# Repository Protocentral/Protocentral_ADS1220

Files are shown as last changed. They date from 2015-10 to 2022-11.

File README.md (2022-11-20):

# ProtoCentral ADS1220 24-bit ADC Breakout Board


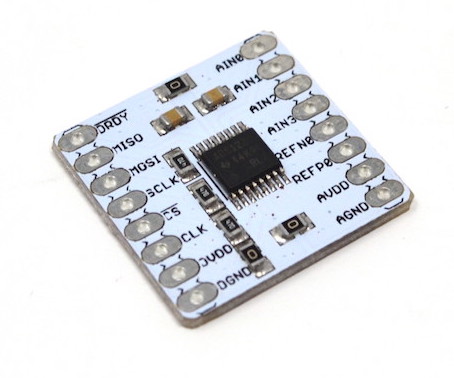
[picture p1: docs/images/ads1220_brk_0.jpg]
ADS1220 Breakout


If you don't already have one, you can buy the ProtoCentral ADS1220 24-bit ADC Breakout Board from: [ProtoCentral(Worldwide)](https://protocentral.com/product/ads1220-24-bit-4-channel-low-noise-adc-breakout-board/)

Why would you need a 24-bit ADC? When 16-bit is just not enough.
If your design demands high precision analog measurements, this new breakout board for the ADS1220 24-bit Sigma-delta ADC can get the job done.
Most of the previously available 24-bit ADCs have been difficult to use since they require a separate voltage reference and a lot of external components among other things. The ADS1220 gets rid of almost all external components with an internal voltage reference and internal clock. This is one of the easiest to use 24-bit ADCs that we have come across.
We also provide the Arduino libraries for interfacing this chip with your Arduino. To install the library, download the zip file from our github site, rename it to ProtoCentral_ADS1220 and unzip this file in your Arduino libraries folder.

## Features

* Programmable Data Rates: Up to 2 kSPS
* Programmable Gain: 1 V/V to 128 V/V
* Low current : 250 uA
* Low-Noise: 90 nVRMS at 20 SPS

## Applications

* High Precision analog voltage measurement
* RTD interfacing
* High precision chemical sensors

## Wiring to your Arduino

|ADS1220 Pin | Pin Function |Arduino Uno Pin Connection|
|---|:---:|---:|
| DRDY | Data ready Output pin|  D2 | 
| MISO | Slave Out |  D12 |
| MOSI | Slave In |  D11 |
| SCLK | Serial Clock |  D13 |
| CS | Chip Select |  D7 |
| DVDD | Digital VDD |  +5V |
| DGND | Digital Gnd |  Gnd |
| AN0-AN3 | Analog Input |  Analog Input |
| AVDD | Analog VDD |  - |
| AGND | Analog Gnd |  - |

  ** The example sketch is configured for internal Vref=2.048, provide the differential voltage across AN0 and AN1.

License Information
===================

License

This product is open source! Both, our hardware and software are open source and licensed under the following licenses:

Hardware
---------

**All hardware is released under the [CERN-OHL-P v2](https://ohwr.org/cern_ohl_p_v2.txt)** license.

Copyright CERN 2020.

This source describes Open Hardware and is licensed under the CERN-OHL-P v2.

You may redistribute and modify this documentation and make products
using it under the terms of the CERN-OHL-P v2 (https:/cern.ch/cern-ohl).
This documentation is distributed WITHOUT ANY EXPRESS OR IMPLIED
WARRANTY, INCLUDING OF MERCHANTABILITY, SATISFACTORY QUALITY
AND FITNESS FOR A PARTICULAR PURPOSE. Please see the CERN-OHL-P v2
for applicable conditions

Software
--------

**All software is released under the MIT License(http://opensource.org/licenses/MIT).**

THE SOFTWARE IS PROVIDED "AS IS", WITHOUT WARRANTY OF ANY KIND, EXPRESS OR IMPLIED, INCLUDING BUT NOT LIMITED TO THE WARRANTIES OF MERCHANTABILITY, FITNESS FOR A PARTICULAR PURPOSE AND NONINFRINGEMENT. IN NO EVENT SHALL THE AUTHORS OR COPYRIGHT HOLDERS BE LIABLE FOR ANY CLAIM, DAMAGES OR OTHER LIABILITY, WHETHER IN AN ACTION OF CONTRACT, TORT OR OTHERWISE, ARISING FROM, OUT OF OR IN CONNECTION WITH THE SOFTWARE OR THE USE OR OTHER DEALINGS IN THE SOFTWARE.

Documentation
-------------
**All documentation is released under [Creative Commons Share-alike 4.0 International](http://creativecommons.org/licenses/by-sa/4.0/).**


You are free to:

* Share — copy and redistribute the material in any medium or format
* Adapt — remix, transform, and build upon the material for any purpose, even commercially.
The licensor cannot revoke these freedoms as long as you follow the license terms.

Under the following terms:

* Attribution — You must give appropriate credit, provide a link to the license, and indicate if changes were made. You may do so in any reasonable manner, but not in any way that suggests the licensor endorses you or your use.
* ShareAlike — If you remix, transform, or build upon the material, you must distribute your contributions under the same license as the original.

Please check [*LICENSE.md*](LICENSE.md) for detailed license descriptions.

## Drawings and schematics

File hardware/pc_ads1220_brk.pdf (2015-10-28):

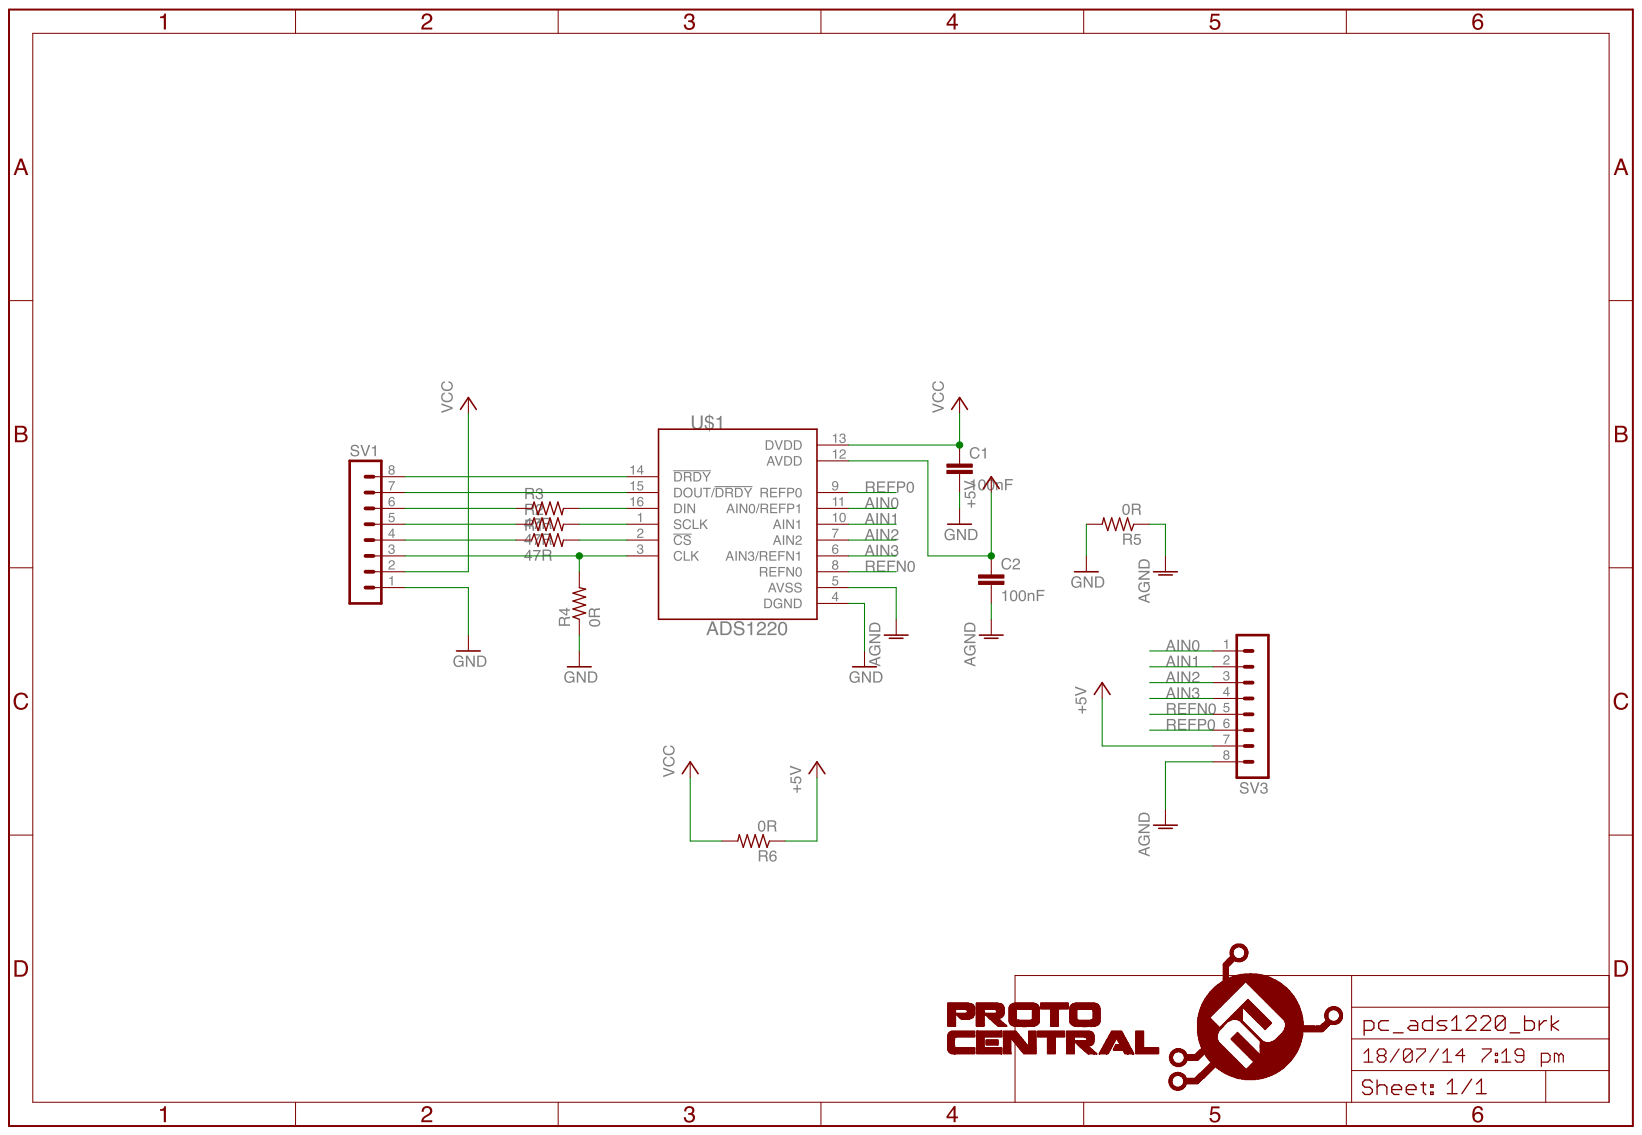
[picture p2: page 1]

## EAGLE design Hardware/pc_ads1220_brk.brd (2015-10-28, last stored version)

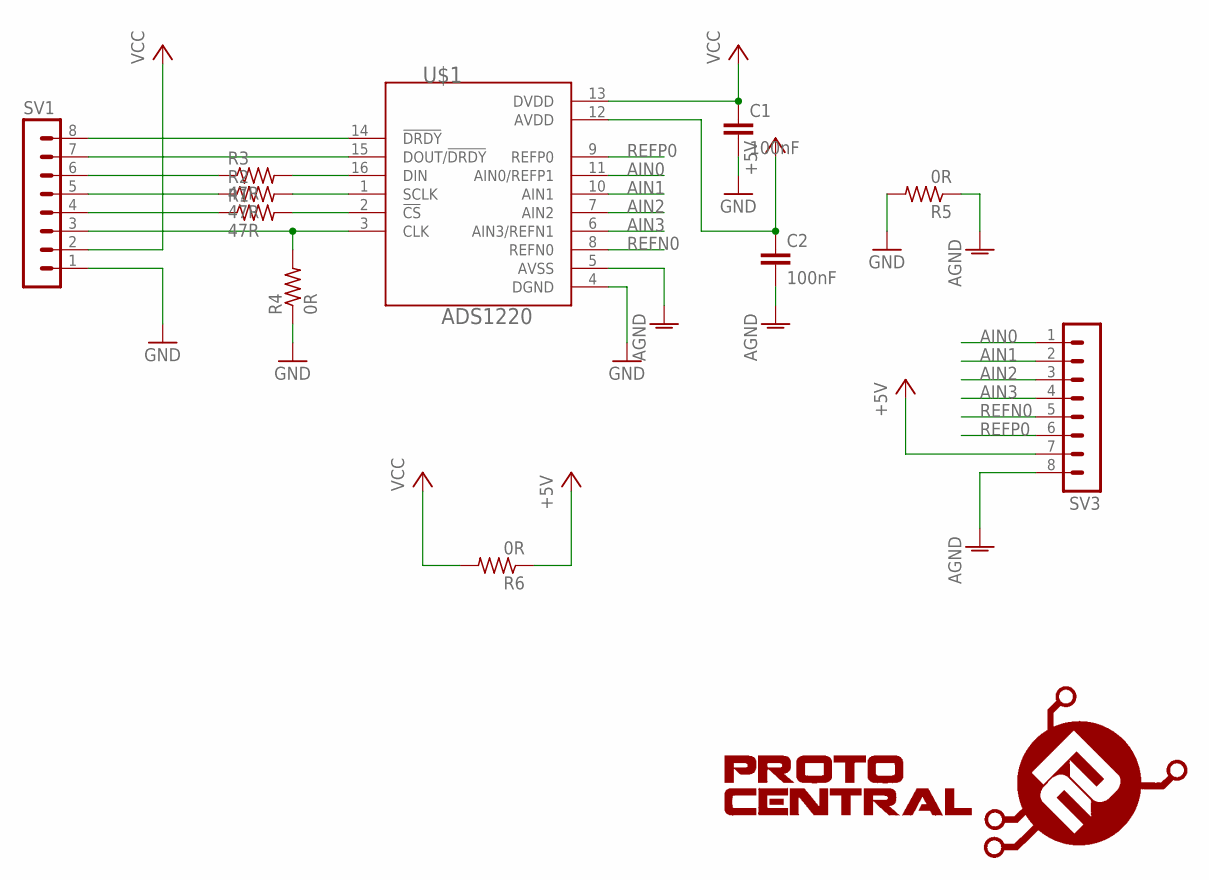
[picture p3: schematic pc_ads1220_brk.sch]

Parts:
C1, C2: 100nF; C0805
R1, R2, R3: 47R; R0805
R4, R5, R6: 0R; R0805
SV1, SV3: MA08-1
U$1: ADS1220; TSSOP-16
U$3: PROTY_LOGO_WITH_TEXT; PROTY_WITH_TEXT

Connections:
+5V: C2.1, R6.1, SV3.7, U$1.12 (AVDD)
AGND: C2.2, R5.1, SV3.8, U$1.5 (AVSS)
AIN0: SV3.1, U$1.11 (AIN0/REFP1)
AIN1: SV3.2, U$1.10 (AIN1)
AIN2: SV3.3, U$1.7 (AIN2)
AIN3: SV3.4, U$1.6 (AIN3/REFN1)
GND: C1.2, R4.1, R5.2, SV1.1, U$1.4 (DGND)
unnamed: R3.1, SV1.6
unnamed: R2.1, SV1.5
unnamed: R3.2, U$1.16 (DIN)
unnamed: R2.2, U$1.1 (SCLK)
unnamed: R1.2, U$1.2 (!CS)
unnamed: R1.1, SV1.4
unnamed: R4.2, SV1.3, U$1.3 (CLK)
unnamed: SV1.7, U$1.15 (DOUT/!DRDY)
unnamed: SV1.8, U$1.14 (!DRDY)
REFN0: SV3.5, U$1.8 (REFN0)
REFP0: SV3.6, U$1.9 (REFP0)
VCC: C1.1, R6.2, SV1.2, U$1.13 (DVDD)

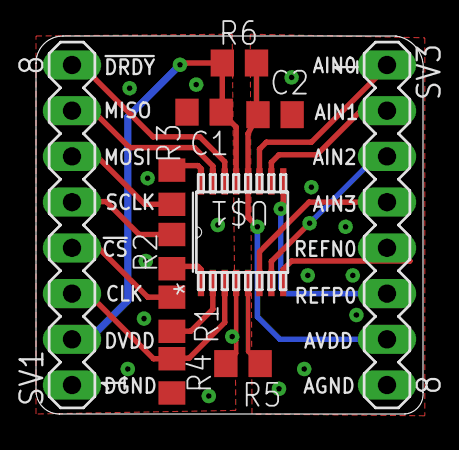
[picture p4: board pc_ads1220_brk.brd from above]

Board: 4 copper layers, 21.5 x 21.0 mm, 12 parts (1 on the bottom side), 19 nets.

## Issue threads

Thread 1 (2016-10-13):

Should support SPI transaction.

xmenxwk, 2016-10-13:
Thats it.

VenkateshBhat, 2016-10-13:
Yes, it does support SPI protocol.

xmenxwk, 2016-10-16:
Wow you were so eager to close the issue you didn't even read. I said "SPI transaction", google it before writing anything.

Closed 2016-10-13.

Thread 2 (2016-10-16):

Few more issues in library

xmenxwk, 2016-10-16:
- Do not use Serial in your library without a debug boolean set to false, anyone using the serial for something else, might get the unexpected data.
- Hard coding ADS1220_CS_PIN and ADS1220_DRDY_PIN is not a good idea. Use constructor to get these pin values.
- There is no way to read single pin input.

protocentralashwin, 2018-06-17:
Thank you @xmenxwk , we are correcting this and all other issues in the new release of the library

Closed 2018-06-17.

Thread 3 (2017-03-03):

Unable to add library in arduino 1.6.12

sdrshnptl, 2017-03-03:
While adding zip library from
Sketch>>Include library>> Add .ZIP library

following error prompt
`Specified folder/zip file does not contain a valid library`

Closed 2018-06-17.

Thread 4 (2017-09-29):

Bad NewDataAvailable test in example/Basic

JRDavisUF, 2017-09-29:
There is an issue in  Protocentral_ADS1220/Libraries/examples/Basic/Protocentral_ADS1220.ino
which causes values to be output as "new" samples when they are *not* new.

Currently line 54 is:
if(ADS1220.NewDataAvailable = true)

This is not actually a test, it just assigns the ADS1220.NewDataAvailable flag to true.  As such, this test statement always evaluates as true and a value is taken from the pointer and output to the screen as if it were a fresh ADC conversion.

This line should be
if(ADS1220.NewDataAvailable == true)

You can see this problem if you setup continuous sampling using the default 20pps and then try to sample faster than that.  For example, replace the delay(300) with delay (10).

protocentralashwin, 2018-06-17:
Thank you @JRDavisUF , we are in the process of creating a new library for this part.

Closed 2018-06-17.

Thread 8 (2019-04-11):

Sampling not sincronized

AlbiBone, 2019-04-11:
Hello, I am using this library but I have some problems with the sincronization of the data-rate coming from the ADS1220 and the reading-rete of my Arduino.
Basically the Arduino loop is executed too fast in comparison than the data-rate and therefore I get a lot of samples that are 0.00 mV between one "real" sample and the other. See the attached picture:
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

It look like that the execution do not wait new data coming from the ADS1220.

Here is the code I'm using.

`//////////////////////////////////////////////////////////////////////////////////////////
//
//    Demo code for the ADS1220 24-bit ADC breakout board
//
//    Author: Ashwin Whitchurch
//    Copyright (c) 2018 ProtoCentral
//
//    This example gives differential voltage across the AN0 and AN1 pins in mVolts
//
//    Arduino connections:
//
//  |ADS1220 pin label| Pin Function         |Arduino Connection|
//  |-----------------|:--------------------:|-----------------:|
//  | DRDY            | Data ready Output pin|  D6              |
//  | MISO            | Slave Out            |  D12             |
//  | MOSI            | Slave In             |  D11             |
//  | SCLK            | Serial Clock         |  D13             |
//  | CS              | Chip Select          |  D7              |
//  | DVDD            | Digital VDD          |  +5V             |
//  | DGND            | Digital Gnd          |  Gnd             |
//  | AN0-AN3         | Analog Input         |  Analog Input    |
//  | AVDD            | Analog VDD           |  -               |
//  | AGND            | Analog Gnd           |  -               |
//
//    This software is licensed under the MIT License(http://opensource.org/licenses/MIT).
//
//   THE SOFTWARE IS PROVIDED "AS IS", WITHOUT WARRANTY OF ANY KIND, EXPRESS OR IMPLIED, INCLUDING BUT
//   NOT LIMITED TO THE WARRANTIES OF MERCHANTABILITY, FITNESS FOR A PARTICULAR PURPOSE AND NONINFRINGEMENT.
//   IN NO EVENT SHALL THE AUTHORS OR COPYRIGHT HOLDERS BE LIABLE FOR ANY CLAIM, DAMAGES OR OTHER LIABILITY,
//   WHETHER IN AN ACTION OF CONTRACT, TORT OR OTHERWISE, ARISING FROM, OUT OF OR IN CONNECTION WITH THE
//   SOFTWARE OR THE USE OR OTHER DEALINGS IN THE SOFTWARE.
//
//   For information on how to use, visit https://github.com/Protocentral/Protocentral_ADS1220
//
/////////////////////////////////////////////////////////////////////////////////////////

#include "Protocentral_ADS1220.h"
#include <SPI.h>

#define PGA 1                 // Programmable Gain = 1
#define VREF 3.300            // Internal reference of 2.048V
#define VFSR VREF/PGA
#define FSR (((long int)1<<23)-1)

#define ADS1220_CS_PIN    7
#define ADS1220_DRDY_PIN  6

Protocentral_ADS1220 pc_ads1220;
int32_t adc_data;

void setup(){
    Serial.begin(115200);

    pc_ads1220.begin(ADS1220_CS_PIN,ADS1220_DRDY_PIN);

    pc_ads1220.set_data_rate(DR_20SPS);
    pc_ads1220.set_pga_gain(PGA_GAIN_1);
    pc_ads1220.select_mux_channels(MUX_AIN0_AIN1);  //Configure for differential measurement between AIN0 and AIN1
    pc_ads1220.set_conv_mode_continuous();
    pc_ads1220.writeRegister(0x02, 0xD0);             // Register #2 (11 = analog supply reference,
                                                      //              01 = Simultaneous 50-Hz and 60-Hz rejection.
                                                      //               0 = Switch is always open (default)
                                                      //              000 = IDAC current setting Off (default)

    pc_ads1220.Start_Conv();  //Start continuous conversion mode
}

void loop(){
  while(true){
    adc_data=pc_ads1220.Read_WaitForData();

    float Vout = (float)((adc_data*VFSR*1000)/FSR);     //In  mV

    Serial.print("t = ");Serial.print(millis());Serial.print(" ms,  V = ");Serial.print(Vout);Serial.println(" mV");
 }
}

`

kutukvpavel, 2020-10-31:
Well, I stumbled upon this strange design decision too (good thing I looked at the code before trying to use the lib). The "WaitForData" name of the functions is actually very misleading. Under the hood there's no wait cycle, just an if statement, that returns 0 if the data is not ready yet, so you are supposed to create your own wait cycle, kinda like:

`ads1220.Start_Conv();
int32_t data;
while ((data = ads1220.Read_WaitForData(), data) == 0);
Serial.println(data);`

God knows why the developers have implemented it this way. The library in general looks unfinished, to say the least. For example, field "NewDataAvailable" is defined, but never used. There are nested includes (cpp file includes headers already included in the .h file...), they don't hurt, but are completely redundant.

Personally, since we have defined DRDY pin in our own code, I would've written the wait cycle like this (though _WaitForData starts to look even more WTFish here):

`ads1220.Start_Conv();
while(digitalRead(your_DRDY_definition_here));
int32_t data = ads1220.Read_WaitForData();
Serial.println(data);`

This library is more like a nice template you can start development with, that has all necessary constants declared and SPI mechanics hidden. But you'll still have to extend it.

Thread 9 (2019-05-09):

Trying to use this with Geophone SM-24

justinklchan, 2019-05-09:
I am trying to use the ADS1220 with the Geophone SM-24, originally as part of this tutorial:
https://create.arduino.cc/projecthub/team-protocentral/measuring-seismic-activity-using-protocentral-openpressure-702324

Here is the link of a signal I get when I wire it up: https://i.imgur.com/hNdHcuM.png
Do you know what the issue could be? It seems squarish, with lots of 0 values.

The ADC seems to saturate when pick up and shake the geophone gently. Is this normal? Anyone know what could be causing this?

Sivolday, 2020-03-12:
I was had the same problem. I added two resistors the problem was solved. It doesn’t matter if the sensor is a thermocouple or a geophone.

Interestingly, did you find a solution? I spent a few days on it.

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

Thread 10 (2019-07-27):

am I drawing too much current on analog inputs?

sensorplay, 2019-07-27:
I have a pressure sensor hooked up and want to ensure it does not draw too much current.

The ADS1220 datasheet lists current sources as 10-1500 microamps. If I understand this correctly, A+/A- can only source 1.5mA to the wheatstone bridge?

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

My A+/A- has a resistance across of ~300 Ohms.

With nominal voltages (5v, 3.3v, etc), will my pressure sensor over-draw?

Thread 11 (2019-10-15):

Struggling with getting it to work...

Decee1, 2019-10-15:
Hello.
I have a PCB that i have designed myself where the \DRDY pin is not used as i use the Data out\DRDY function.
If i modify the m_config_reg3 default setting it should in theory
m_config_reg3 = 0x02;
Notes: Microcontroller is ATMega328p with 8MHz crystal (normal 16MHz) but i do have other SPI things that work on it so this should also work
Current pinout:
CS on 8
MOSI on 11
MISO/DRDY on 12
SCK on 13

Do you have any idea why this is not working?
When printing all the config registers they all are "FF" so it seems like it doesn't really work..

Decee1, 2019-10-15:
Figured it out. Just a bad soldering joint. So much for not being able to use my own equipment at home..

Closed 2019-10-15.

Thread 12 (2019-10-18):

Running multiple SPI devices CAN give some issues.

Decee1, 2019-10-18:
Hello.

I've been struggling with figuring out why the heck my ILI9340 and ADS1220 wouldn't go nice together. It took A LONG time to figure it out but i realized that the ILI9340 runs with another clock divider so the clock speed is much fast er than allowed on the ADS1220. In a nutshell.. IT WONT WORK.

A solution is redoing the library transfer parts to use this kind of transfer which sets the MSB, spi mode and clock for each transaction to ensure it is ok. I am going to do this myself right now so it shouldn't be hard.
https://www.arduino.cc/en/Tutorial/SPITransaction

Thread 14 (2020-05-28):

Add software SPI support

OneGneissGuy, 2020-05-28:
Sometimes the hardware SPI port is already taken from another and incompatible SPI device, so adding software "bit-banging" SPI support to this library would be a nice feature.

OneGneissGuy, 2020-06-02:
Solved by passing pins to `SPI.begin()`
```cpp
SPI.begin(SCK,MISO,MOSI,CS)
```

Closed 2020-06-02.

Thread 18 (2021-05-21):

Question about unprecise messurment

MADxHAWK, 2021-05-21:
I recently bought a ads1220 module and tested it connected to an ESP32 (Heltec Wifi Kit32)
As an input i used a 100k potentiometer between VDD and GND where the output is connected to Ain0.
Usind the default example compared to a precise Benchtop Multimeter i have a difference between the messurment of the ADC and the Multimeter of about 5-6mV at an inputvoltage between 0 and 200 mV
The ADC uses the +3.3V and GND of the ESP32 as supplyvoltage.
I think for a 24Bit ADC 5-6mV is a quite high difference between the messurments of the ADC and the Multimeter with an accuracy of 4 1/2 Digit 20000 Count +/-0.03% +3
Even the 16Bit ADS1115 giving me a more accurate reading then the 24Bit ADS1220.
So did i maybe got a faked Chip / Module?

dottoreD, 2021-07-20:
Can you exclude for sure that you don't have a systematic issue with your test setup? Starting with VDD is assumed to me a not good enough source to generate error free test voltage.

MADxHAWK, 2021-11-20:
Sorry havent been around for quite some time.
Well the supplyvoltage for the ADC is quite stable at about 3.3V +/- 50mv or so, but with some noise from the powersupply.
Its not a pressision voltage source anyway.

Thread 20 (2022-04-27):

Startup problem with battery

AndreasLamparter, 2022-04-27:
Hi,

Hardware:
Adafruit Feather Sense
ProtoCentral ADS1220
3.7v Lipo 300mAh / 600mAh

If i start with USB connected the ADS library returns valid values.
If i start with battery only, the ADS library returns nan .
If i start with USB connected, disconnect USB (the adafruit are now powered by battery) the lib returns valid values.
The values are send over ble.

Is there an inrush problem ?

Best regards
Andreas

Closed 2022-06-22.

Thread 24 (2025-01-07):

Two ADS1220 modules not working on an Arduino UNO R4 Minima and WiFi

wollewald, 2025-01-07:
Hi,

there is a strange issue when using two ADS1220 modules controlled by an Arduino UNO R4 Minima or WiFi. The two devices are attached correctly to the Arduino.

I have a applied the following sketch:

````
#include "Protocentral_ADS1220.h"
#include <SPI.h>

#define PGA 1                // Programmable Gain, confirm that the same as set_pga_gain
#define VREF 2.048            // Internal reference of 2.048V
#define VFSR VREF/PGA
#define FSR (((long int)1<<23)-1)

#define ADS1220_CS_1_PIN    7
#define ADS1220_DRDY_1_PIN  2
#define ADS1220_CS_2_PIN    6
#define ADS1220_DRDY_2_PIN  3

Protocentral_ADS1220 pc_ads1220_1;
Protocentral_ADS1220 pc_ads1220_2;

int32_t adc_data;
volatile bool drdyIntrFlag_1 = false;
volatile bool drdyIntrFlag_2 = false;

void drdyInterruptHndlr_1(){
  drdyIntrFlag_1 = true;
}

void drdyInterruptHndlr_2(){
  drdyIntrFlag_2 = true;
}

void enableInterruptPins(){
  attachInterrupt(digitalPinToInterrupt(ADS1220_DRDY_1_PIN), drdyInterruptHndlr_1, FALLING);
//   attachInterrupt(digitalPinToInterrupt(ADS1220_DRDY_2_PIN), drdyInterruptHndlr_2, FALLING);
}

void setup()
{
  Serial.begin(115200);

  // Avoid intializazion of the wrong module
  pinMode(ADS1220_CS_1_PIN, OUTPUT);
  digitalWrite(ADS1220_CS_1_PIN, HIGH); // Inicialmente CS inactivo
  pinMode(ADS1220_CS_2_PIN, OUTPUT);
  digitalWrite(ADS1220_CS_2_PIN, HIGH); // Inicialmente CS inactivo

  // Set up ADS1220 #1
  pc_ads1220_1.begin(ADS1220_CS_1_PIN,ADS1220_DRDY_1_PIN);
  pc_ads1220_1.set_data_rate(DR_20SPS);
  pc_ads1220_1.set_pga_gain(PGA_GAIN_1);
  pc_ads1220_1.select_mux_channels(MUX_AIN0_AIN1);  //Configure for differential measurement between AIN0 and AIN1
  pc_ads1220_1.set_conv_mode_continuous();          //Set continuous conversion mode
  pc_ads1220_1.Start_Conv();  //Start continuous conversion mode

  // Set up ADS1220 #2
  pc_ads1220_2.begin(ADS1220_CS_2_PIN,ADS1220_DRDY_2_PIN);
//   pc_ads1220_2.set_data_rate(DR_20SPS);
//   pc_ads1220_2.set_pga_gain(PGA_GAIN_1);
//   pc_ads1220_2.select_mux_channels(MUX_AIN0_AIN1);  //Configure for differential measurement between AIN0 and AIN1
//   pc_ads1220_2.set_conv_mode_continuous();          //Set continuous conversion mode
//   pc_ads1220_2.Start_Conv();  //Start continuous conversion mode

  enableInterruptPins();
}

void loop()
{
  if(drdyIntrFlag_1){
    drdyIntrFlag_1 = false;
    adc_data=pc_ads1220_1.Read_Data_Samples();
    float Vout = (float)((adc_data*VFSR*1000)/FSR);     //In  mV
    delay(1000);
    Serial.print("Vout #1 in mV : ");
    Serial.println(Vout);
  }
//   if(drdyIntrFlag_2){
//     drdyIntrFlag_2 = false;
//     adc_data=pc_ads1220_2.Read_Data_Samples();
//     float Vout = (float)((adc_data*VFSR*1000)/FSR);     //In  mV
//     delay(1000);
//     Serial.print("Vout #2 in mV : ");
//     Serial.println(Vout);
//   }
}
````

The sketch should display correct voltages (0 - 2.048 V) attached to AIN0/AIN1 for the ADS1220 #1. But the result is wrong. The same sketch works well with the Arduino UNO R3. If you comment out just that one line, you will get a correct result:
````
 pc_ads1220_1.begin(ADS1220_CS_1_PIN,ADS1220_DRDY_1_PIN);
````

If you uncomment all relevant lines for ADS1220 #2 and run the sketch on an Arduino UNO R3, you will get correct results for both the ADS1220 #1 and #2. That makes me confident that there is no issue with the wiring which was exactly the same for the trials with the Arduino UNO R4.

To be be honest I did not find the issue myself. I have an own library for the ADS1220 and a user found exactly the same problem with my one:
https://github.com/wollewald/ADS1220_WE  / https://github.com/wollewald/ADS1220_WE/issues/5
I have spent lots of hours trying to find the root cause but failed.

It is basically possible to communicate with the two ADS1220 devices when using an Arduino UNO R4. For this, I have tried to write data in config 0 register of the two devices an then read it back. This works fine:

````
#include <SPI.h>

#define ADS1220_1_CS_PIN    7   // Chip Select
#define ADS1220_2_CS_PIN    5   //
SPISettings mySPISettings(4000000, MSBFIRST, SPI_MODE1);

void setup() {
  Serial.begin(115200);
  while (!Serial);
  Serial.println("Initializing ADS1220 #1 and #2 ...");
  SPI.begin();

  // Avoid intializazion of the wrong module
  pinMode(ADS1220_1_CS_PIN, OUTPUT);
  digitalWrite(ADS1220_1_CS_PIN, HIGH);
  pinMode(ADS1220_2_CS_PIN, OUTPUT);
  digitalWrite(ADS1220_2_CS_PIN, HIGH);

  delay(100);

  // write/read some dummy values into/from Config 0 register
  writeConfig0(ADS1220_1_CS_PIN); // write into ADS1220 #1
  readADS1220(ADS1220_1_CS_PIN);  // read from ADS1220 #1
  writeConfig0(ADS1220_2_CS_PIN); // write into ADS1220 #2
  readADS1220(ADS1220_2_CS_PIN);  // read from ADS1220 #2
  readADS1220(ADS1220_1_CS_PIN);  // read from ADS1220 #1 (double check)
}

void loop() {
  delay(1000);
}

void writeConfig0(int csPin) {
  // force Reset
  SPI.beginTransaction(mySPISettings);
  digitalWrite(csPin, LOW); // activate CS
  SPI.transfer(0x06); // Reset command
  digitalWrite(csPin, HIGH); // deactivate CS
  SPI.endTransaction();
  delayMicroseconds(50);

  // write something into Config 0 reg.
  SPI.beginTransaction(mySPISettings);
  digitalWrite(csPin, LOW); //  activate CS
  SPI.transfer(0x40 | (0x00 << 2));
  if(csPin == ADS1220_1_CS_PIN){
    SPI.transfer(0x03); // PGA bypass and gain = 2
  }
  else{
    SPI.transfer(0x01);  // PGA bypass
  }
  digitalWrite(csPin, HIGH); // deactivate CS
  SPI.endTransaction();
}

void readADS1220(int csPin){
  SPI.beginTransaction(mySPISettings);
  digitalWrite(csPin, LOW); //  activate CS
  SPI.transfer(0x20 | (0x00 << 2));
  byte config0 = SPI.transfer(0x00);
  digitalWrite(csPin, HIGH); // deactivate CS
  SPI.endTransaction();
  if(csPin == ADS1220_1_CS_PIN){
    Serial.print("Config Register 0 (ADS1220 #1): 0x");
  }
  else {
    Serial.print("Config Register 0 (ADS1220 #2): 0x");
  }
  Serial.println(config0, HEX);
}
````

This works correctly on the UNO R3 and R4.

Do you have any idea?

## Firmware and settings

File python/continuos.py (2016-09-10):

#!/usr/bin/env python
print "test"

import spidev
import time
import sys
import RPi.GPIO as GPIO
from array import *


RREG =   0x20;
WREG  =  0x40;
START=0x08
STOP=0x0A
RDATAC=      0x10 

SDATAC	=	0x11	
RDATA	=	0x12


GPIO.setmode(GPIO.BOARD)


DRDY_PIN = 13;
START_PIN = 15;
CS_PIN = 18
RESET_PIN = 16


GPIO.setwarnings(False);

GPIO.setup(CS_PIN,GPIO.OUT)

GPIO.setup(DRDY_PIN,GPIO.IN)

spi = spidev.SpiDev()				# create spi object
spi.open(0,1)					# open spi port 0, device (CS)1
spi.max_speed_hz = (500000)
spi.mode = (1)

print "test"




count = 0

def Reg_Write(address,data):    # write Fibonacci series up to 
	print ("Writing %s to Register %s" %( hex(data),hex(address)))
	print(data);


	opcode1 = (address<<2) | 0x40

	GPIO.output(CS_PIN, False)
	time.sleep(0.002)               # sleep for 0.1 seconds
	GPIO.output(CS_PIN, True)
	time.sleep(0.002)               # sleep for 0.1 seconds

	GPIO.output(CS_PIN, False)
	time.sleep(0.002)               # sleep for 0.1 seconds
	resp = spi.xfer2([opcode1])        # transfer one byte
	resp = spi.xfer2([data])        # transfer one byte
	time.sleep(0.002)               # sleep for 0.1 seconds
	GPIO.output(CS_PIN, True)
	return;

def Reg_read(address):    # write Fibonacci series up to
	print ("Reading from Register %s" %(hex(address)))
        opcode1 = address | 0x20

        GPIO.output(CS_PIN, False)
        time.sleep(0.002)               # sleep for 0.1 seconds
        GPIO.output(CS_PIN, True)
        time.sleep(0.002)               # sleep for 0.1 seconds

        GPIO.output(CS_PIN, False)
        time.sleep(0.002)               # sleep for 0.1 seconds
        resp = spi.xfer2([opcode1])        # transfer one byte
        resp = spi.xfer2([0xff])        # transfer one byt
        time.sleep(0.002)               # sleep for 0.1 seconds
        GPIO.output(CS_PIN, True)

	#print("Data read is %s" %(hex(resp)))
	print(resp);
	return;

def Spi_command(command):    # write Fibonacci series up to
        GPIO.output(CS_PIN, False)
        time.sleep(0.002)               # sleep for 0.1 seconds
        GPIO.output(CS_PIN, True)
        time.sleep(0.002)               # sleep for 0.1 seconds

        GPIO.output(CS_PIN, False)
        time.sleep(0.002)               # sleep for 0.1 seconds
        resp = spi.xfer2([command])        # transfer one byte
        time.sleep(0.002)               # sleep for 0.1 seconds
        GPIO.output(CS_PIN, True)

        return;


def initialisation1():  
	print ("INITIALISATION");
	#GPIO.output(CS_PIN, False)

 

	Spi_command(START);				
	time.sleep(0.1);
	Spi_command(STOP);				
	time.sleep(0.1);

	Spi_command(SDATAC);				
	time.sleep(0.3);

	Reg_Write(0x00, 0x01); 		
	time.sleep(0.01); 
	Reg_Write(0x01, 0x04);	
	time.sleep(0.01); 
	Reg_Write(0x02, 0x10);		
	time.sleep(0.01); 
	Reg_Write(0x03, 0x00);	
	time.sleep(0.01); 
	
	Reg_read(0x00);
	time.sleep(0.1);
	Reg_read(0x04);
	time.sleep(0.1);
	Reg_read(0x08);
	time.sleep(0.1);
	Reg_read(0x0c);
	


        
	Spi_command(RDATAC);				
	time.sleep(0.3); 

	Spi_command(START);
	time.sleep(0.1);
	 

	GPIO.output(CS_PIN, True)
	return;

'''def Regread(arg1):
        # Add both the parameters and return them."
        total = arg1 + 67
        print "Inside the function : ", total
        return total;
'''
# Now you can call sum function
'''try:
        while True:
                total = sum( 10,20 );
                print "Outside the function : ", total
except KeyboardInterrupt:                       # Ctrl+C pressed, so...
        spi.close()                             # ... close the port before exit
'''
def toHex(dec):
	x = (dec % 16)
	digits = "0123456789ABCDEF"
	rest = dec / 16
	if (rest == 0):
		return digits[x]
	return toHex(rest) + digits[x]

def initialisation2():

	time.sleep(0.2)
	print "STARTED"

	#GPIO.output(CS_PIN, False)
	resp = spi.xfer2([0x11])        # transfer one byte
	time.sleep(0.3)	
	return;

def Read_Data():
	buff = [0,0,0,0,0,0,0,0,0];
	#buff=array('b',[0,0,0,0,0,0,0,0,0])
	#buff = [];
	GPIO.output(CS_PIN, False)
	#time.sleep(0.001)               # sleep for 0.1 seconds
	#for i in range(0,9):
	buff = spi.xfer2([0xff,0xff,0xff])
	'''buff2 = spi.xfer2([0xff])
	buff3 = spi.xfer2([0xff])'''
	#buff[i] = buffer[0]
	#print("%x" %buffer[0])	
	'''channel = 1
	r = spi.xfer2([1, (8+channel)<<4, 0])
	#r = spi.xfer2([0xff],[0xff],[0xff],[0xff],[0xff],[0xff],[0xff],[0xff],[0xff])
	r = spi.xfer2([0xff])
	#adcout = ((r[0]&3) << 8)
	#print [(x) for x in buff]'''

	#time.sleep(0.002)               # sleep for 0.1 seconds
	GPIO.output(CS_PIN, True)
	
	print("0x %x %x %x\t"%(buff[0],buff[1],buff[2]))
	value = buff[0]<<16 | buff[1]<<8 | buff[2]
	print(value)
	volt = (float(value) * .000244140625)
        print  volt,"mV"

	#print("0x %x %x %x\t"%(buff[0],buff[1],buff[2]))
	'''print int(buff[0])
	print int(buff[1])'''

	'''print int(buff2[0])
	print int(buff3[0])'''


	return buff;
	#return r

def Read_adcvoltage():
	result = Read_Data()
	return result
	'''val = ((result[5]&0xff) << 16) | ((result[6]&0xff) << 8) | (result[7]&0xff)
	if val > 0x7FFFFF:
		return (val - 0xFFFFFF)*6/8388608.0
	else:
		return ((result[5] << 16) | (result[6] << 8) | (result[7]))*6/8388608.0'''

	
voltage = 0

def ADCRead():
	#global voltage
	while(GPIO.input(DRDY_PIN) == True):
		time.sleep(0.001)		

	if (GPIO.input(DRDY_PIN) == False):
		#if 1:
		data = Read_adcvoltage();
		#val = ((data[5]&0xff) << 16) | ((data[6]&0xff) << 8) | (data[7]&0xff)
		val = ((data[6]&0xff) << 16) + ((data[7]&0xff) << 8) + (data[8]&0xff)
		#val = (data&0xff0000) + (data&0xff00) + (data&0xff)
		val = int(val)

		if( (val&(1<<(24-1))) != 0 ):
			value = val - 0x1000000			
		else:
			value = val
			
		voltage = (float(value)*100/8388607)
	
		#print("DRDY_PIN : %s\nvalue: %s"%((GPIO.input(DRDY_PIN)),value))
		#print "drdy false"
		#print("\t0x %x %x %x\tval: %x, %d\t2'scomp value: %s\tVoltage in mV: %s"%(data[6],data[7],data[8],val,val,value,voltage))
 		#print("Channel 2 value : %s"%(value))
		#time.sleep(.5)               # sleep for 0.1 seconds
		return voltage	
	'''#else:
		#print("DRDY_PIN : %s"%(GPIO.input(DRDY_PIN)))
		#print("DRDY_PIN : %s\nvalue: %s"%((GPIO.input(DRDY_PIN)),value))
		print "drdy true"
		return voltage'''
		#return 0

			
'''except KeyboardInterrupt:                       # Ctrl+C pressed, so...
        spi.close()                             # ... close the port before exit
        print("STOPPED")'''




def generator():
  global values,scale2
  #adc = ADS1x15()
  # Read channel 0 and 1 in single-ended mode (1 bit = 3mV)
  print "start"
  #rint("DRDY_PIN : %s"%(GPIO.input(DRDY_PIN)))

  for i in range(1200):
    #values.append(adc.readADCSingleEnded(0)*0.003)
    #print("DRDY_PIN : %s"%(GPIO.input(DRDY_PIN))
    values.append(ADCRead())
  root.after(int(scale2['to'])-scale2.get(),generator)

def plotter():
  global values,scale1,scale2
  NumberSamples=min(len(values),scale1.get())
  CurrentXAxis=pylab.arange(len(values)-NumberSamples,len(values),1)
  line1[0].set_data(CurrentXAxis,pylab.array(values[-NumberSamples:]))
  ax.axis([CurrentXAxis.min(),CurrentXAxis.max(),range_min,range_max])
  drawing.draw()
  root.after(25,plotter)


def _quit():
    root.quit()     # stops mainloop
    root.destroy()  # this is necessary on Windows to prevent
                    # Fatal Python Error: PyEval_RestoreThread: NULL tstate


initialisation1()
initialisation2()
Read_Data()

while True:

	Read_Data()
	time.sleep(0.5)

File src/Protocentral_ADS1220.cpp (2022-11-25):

//////////////////////////////////////////////////////////////////////////////////////////
//
//    Arduino library for the ADS1220 24-bit ADC breakout board
//
//    Author: Ashwin Whitchurch
//    Copyright (c) 2018 ProtoCentral
//
//    Based on original code from Texas Instruments
//
//    This software is licensed under the MIT License(http://opensource.org/licenses/MIT).
//
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
//   For information on how to use, visit https://github.com/Protocentral/Protocentral_ADS1220/
//
/////////////////////////////////////////////////////////////////////////////////////////

#include <Arduino.h>
#include "Protocentral_ADS1220.h"
#include <SPI.h>
#include <limits.h>

//#define BOARD_SENSYTHING ST_1_3

SPISettings SPI_SETTINGS(2000000, MSBFIRST, SPI_MODE1); 

#ifdef _BV
#undef _BV
#endif

#define _BV(bit) (1<<(bit))


Protocentral_ADS1220::Protocentral_ADS1220() 								// Constructors
{

}

void Protocentral_ADS1220::writeRegister(uint8_t address, uint8_t value)
{
    SPI.beginTransaction(SPI_SETTINGS);
    digitalWrite(m_cs_pin,LOW);
    delayMicroseconds(1);
    SPI.transfer(WREG|(address<<2));
    SPI.transfer(value);
    delayMicroseconds(1);
    digitalWrite(m_cs_pin,HIGH);
    SPI.endTransaction();
}

uint8_t Protocentral_ADS1220::readRegister(uint8_t address)
{
    uint8_t data;

    SPI.beginTransaction(SPI_SETTINGS);
    digitalWrite(m_cs_pin,LOW);
    delayMicroseconds(1);
    SPI.transfer(RREG|(address<<2));
    data = SPI.transfer(SPI_MASTER_DUMMY);
    delayMicroseconds(1);
    digitalWrite(m_cs_pin,HIGH);
    SPI.endTransaction();

    return data;
}

void Protocentral_ADS1220::begin(uint8_t cs_pin, uint8_t drdy_pin)
{
    m_drdy_pin=drdy_pin;
    m_cs_pin=cs_pin;

    pinMode(m_cs_pin, OUTPUT);
    pinMode(m_drdy_pin, INPUT);

#if defined(BOARD_SENSYTHING)
    SPI.begin(18, 35, 23, 19);
#else
    SPI.begin();
    //SPI.setClockDivider(SPI_CLOCK_DIV2);
#endif
    //SPI.setBitOrder(MSBFIRST);
    //SPI.setDataMode(SPI_MODE3);

    ads1220_Reset();
    delayMicroseconds(50);
    
    // The device pulls nDRDY low after it is initialized
    if(!WaitForData(1)){
        // TODO: Handle the timeout
    }

    m_config_reg0 = 0x00;   //Default settings: AINP=AIN0, AINN=AIN1, Gain 1, PGA enabled
    m_config_reg1 = 0x04;   //Default settings: DR=20 SPS, Mode=Normal, Conv mode=continuous, Temp Sensor disabled, Current Source off
    m_config_reg2 = 0x10;   //Default settings: Vref internal, 50/60Hz rejection, power open, IDAC off
    m_config_reg3 = 0x00;   //Default settings: IDAC1 disabled, IDAC2 disabled, DRDY pin only

    writeRegister( CONFIG_REG0_ADDRESS , m_config_reg0);
    writeRegister( CONFIG_REG1_ADDRESS , m_config_reg1);
    writeRegister( CONFIG_REG2_ADDRESS , m_config_reg2);
    writeRegister( CONFIG_REG3_ADDRESS , m_config_reg3);
}

void Protocentral_ADS1220::PrintRegisterValues(){
    Config_Reg0 = readRegister(CONFIG_REG0_ADDRESS);
    Config_Reg1 = readRegister(CONFIG_REG1_ADDRESS);
    Config_Reg2 = readRegister(CONFIG_REG2_ADDRESS);
    Config_Reg3 = readRegister(CONFIG_REG3_ADDRESS);

    Serial.println("Config_Reg : ");
    Serial.println(Config_Reg0,HEX);
    Serial.println(Config_Reg1,HEX);
    Serial.println(Config_Reg2,HEX);
    Serial.println(Config_Reg3,HEX);
    Serial.println(" ");
}

void Protocentral_ADS1220::SPI_Command(unsigned char data_in)
{
    SPI.beginTransaction(SPI_SETTINGS);
    digitalWrite(m_cs_pin, LOW);
    delayMicroseconds(1);
    SPI.transfer(data_in);
    delayMicroseconds(1);
    digitalWrite(m_cs_pin, HIGH);
    SPI.endTransaction();
}

void Protocentral_ADS1220::ads1220_Reset()
{
    SPI_Command(RESET);
}

void Protocentral_ADS1220::Start_Conv()
{
    SPI_Command(START);
}

// control register 0
void Protocentral_ADS1220::select_mux_channels(int channels_conf)
{
    m_config_reg0 &= ~REG_CONFIG0_MUX_MASK;
    m_config_reg0 |= channels_conf;
    writeRegister(CONFIG_REG0_ADDRESS,m_config_reg0);
}

void Protocentral_ADS1220::set_pga_gain(int pgagain)
{
    m_config_reg0 &= ~REG_CONFIG0_PGA_GAIN_MASK;
    m_config_reg0 |= pgagain ;
    writeRegister(CONFIG_REG0_ADDRESS,m_config_reg0);
}

void Protocentral_ADS1220::PGA_ON(void)
{
    m_config_reg0 &= ~_BV(0);
    writeRegister(CONFIG_REG0_ADDRESS,m_config_reg0);
}

void Protocentral_ADS1220::PGA_OFF(void)
{
    m_config_reg0 |= _BV(0);
    writeRegister(CONFIG_REG0_ADDRESS,m_config_reg0);
}

// control register 1
void Protocentral_ADS1220::set_data_rate(int datarate)
{
    m_config_reg1 &= ~REG_CONFIG1_DR_MASK;
    m_config_reg1 |= datarate;
    writeRegister(CONFIG_REG1_ADDRESS,m_config_reg1);
}

void Protocentral_ADS1220::set_OperationMode(int OPmode)
{
    m_config_reg1 &= ~REG_CONFIG1_MODE_MASK;
    m_config_reg1 |= OPmode;
    writeRegister(CONFIG_REG1_ADDRESS,m_config_reg1);
}

void Protocentral_ADS1220::set_conv_mode_single_shot(void)
{
    m_config_reg1 &= ~_BV(2);
    writeRegister(CONFIG_REG1_ADDRESS,m_config_reg1);
}

void Protocentral_ADS1220::set_conv_mode_continuous(void)
{
    m_config_reg1 |= _BV(2);
    writeRegister(CONFIG_REG1_ADDRESS,m_config_reg1);
}

void Protocentral_ADS1220::TemperatureSensorMode_disable(void)
{
    m_config_reg1 &= ~_BV(1);
    writeRegister(CONFIG_REG1_ADDRESS,m_config_reg1);
}

void Protocentral_ADS1220::TemperatureSensorMode_enable(void)
{
    m_config_reg1 |= _BV(1);
    writeRegister(CONFIG_REG1_ADDRESS,m_config_reg1);
}

void Protocentral_ADS1220::CurrentSources_OFF(void)
{
    m_config_reg1 &= ~_BV(0);
    writeRegister(CONFIG_REG1_ADDRESS,m_config_reg1);
}

void Protocentral_ADS1220::CurrentSources_ON(void)
{
    m_config_reg1 |= _BV(0);
    writeRegister(CONFIG_REG1_ADDRESS,m_config_reg1);
}

// control register 2
void Protocentral_ADS1220::set_VREF(int vref)
{
    m_config_reg2 &= ~REG_CONFIG2_VREF_MASK;
    m_config_reg2 |= vref;
    writeRegister(CONFIG_REG2_ADDRESS,m_config_reg2);
}

void Protocentral_ADS1220::set_FIR_Filter(int filter)
{
    m_config_reg2 &= ~REG_CONFIG2_FIR_MASK;
    m_config_reg2 |= filter;
    writeRegister(CONFIG_REG2_ADDRESS,m_config_reg2);
}

void Protocentral_ADS1220::LowSideSwitch_OPEN(void)
{
    m_config_reg2 &= ~_BV(3);
    writeRegister(CONFIG_REG2_ADDRESS,m_config_reg2);
}

void Protocentral_ADS1220::LowSideSwitch_CLOSED(void)
{
    m_config_reg2 |= _BV(3);
    writeRegister(CONFIG_REG2_ADDRESS,m_config_reg2);
}

void Protocentral_ADS1220::set_IDAC_Current(int IDACcurrent)
{
    m_config_reg2 &= ~REG_CONFIG2_IDACcurrent_MASK;
    m_config_reg2 |= IDACcurrent;
    writeRegister(CONFIG_REG2_ADDRESS,m_config_reg2);
}

// control register 3
void Protocentral_ADS1220::set_IDAC1_Route(int IDAC1routing)
{
    m_config_reg3 &= ~REG_CONFIG3_IDAC1routing_MASK;
    m_config_reg3 |= IDAC1routing;
    writeRegister(CONFIG_REG3_ADDRESS,m_config_reg3);
}
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

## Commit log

2014-08-11 Protocentral_ADS1220
    Breakout board for ads1220.
2015-10-28 Arduino Source file and Example Sketch
2015-10-28 Schematic and Design File
    [pc_ads1220_brk.brd, pc_ads1220_brk.sch]
2018-06-19 Fixed issue with chip getting stuck
    [Protocentral_ADS1220.cpp]
2018-10-08 * Remove long delays. * Refactor repeated code. * Add functions to change the voltage reference. * Fix WaitForData * Remove Serial.print from begin()
    [Protocentral_ADS1220.cpp]
2018-10-08 Fix a bug in the reference selection code
    [Protocentral_ADS1220.cpp]
2018-10-09 Use SPI transactions
2021-01-05 added interrupt based read
    [pc_ads1220_brk.brd, pc_ads1220_brk.sch]
2021-02-13 Update Protocentral_ADS1220.cpp
    Added functions to control registers 0 -3 configuration following datasheet, including switching on/off internal Temp-sensor & operation mode etc.
2021-02-13 Update Protocentral_ADS1220.h
    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

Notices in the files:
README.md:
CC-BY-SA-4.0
